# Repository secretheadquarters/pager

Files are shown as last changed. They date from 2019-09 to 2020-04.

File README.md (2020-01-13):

# pager

Raspberry Pi project to act as a kind of pager (or secret communication device)

# Overview

* Raspberry Pi Zero W
 * Connected to red and green LEDs through GPIO
 * With a 20x2 LCD display screen
 * And various extra addons over time (I'm planning a buzzer, USB storage, USB (or Bluetooth) audio, and maybe more)

# Raspberry Pi setup
* Download latest image and write to SD card. 

## On a Linux machine
```
  sudo su
  apt-get install funzip
  
  # Insert SD card
  dmesg 
  # Look at output to work out what device the SD card was recognised as
  
  # Download the latest raspbian image and unzip direct to the sd card 
  # (replace /dev/sdc with the appropriate device)
  wget -O - https://downloads.raspberrypi.org/raspbian_lite_latest | funzip > /dev/sdc
```
## On a Windows machine
* Downnload the image file: https://downloads.raspberrypi.org/raspbian_lite_latest
* Write to an SD card using [Etcher](https://www.balena.io/etcher/)

## Create an email account for the pager
* If you're using gmail:
  * Turn on two-factor authentication
  * Generate an "App Password"

## Configure the SD card
* Copy the files from the [setup/boot] folder to the boot partiton
  * Add an empty file called `ssh` to the boot partition
  * Add a file called `wpa_supplicant.conf` to the boot partition, and fill with your WiFi settings
  * Make sure you use Unix line endings (\n)

## Install the software
* Turn the Raspberry Pi on
* By default, it will appear on the network as "raspberrypi"
* Log in using the standard Raspbian username and password
* Configure the system by downloading the setup script and running it:
  * `curl https://raw.githubusercontent.com/secretheadquarters/pager/master/setup/setup.sh --output setup.sh && chmod +x setup.sh && ./setup.sh`

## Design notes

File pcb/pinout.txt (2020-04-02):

LCD header
----------
GPIO14    DB7   1   2  DB6   GPIO2
GPIO15    DB5   3   4  DB4   GPIO3
GPIO18    DB3   5   6  DB2   GPIO4
GPIO23    DB1   7   8  DB0   GPIO17
GPIO24     E1   9  10  RW    GND
GPIO25     RS  11  12  VO    Contrast 
GND       VSS  13  14  VDD   +5V
GPIO8      E2  15  16  NC
Backlight   A  17  18  K     GND

Buttons header
--------------
Pressing button connects to GND.
Use GPIO with pull-up resistor enabled.

B1  GPIO7
B2  GPIO12
B3  GPIO16

Output header
-------------
Connect red and green LED
Header connects to open-collector NPN transistor
A high signal on GPIO turns transistor on
O1  GPIO21
O2  GPIO20

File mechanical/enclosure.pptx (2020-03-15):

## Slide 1

⌀ 14

⌀ 3.5

Hammond 1591XXDBK FRABS Enclosure 152 x 82 x 50mm Black
Winstar WH2002A-YYH-JT 20x2 LCD Display Yellow/green LED Backlight

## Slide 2

⌀ 16

Hammond 1591XXDBK FRABS Enclosure 152 x 82 x 50mm Black
Winstar WH2002A-YYH-JT 20x2 LCD Display Yellow/green LED Backlight

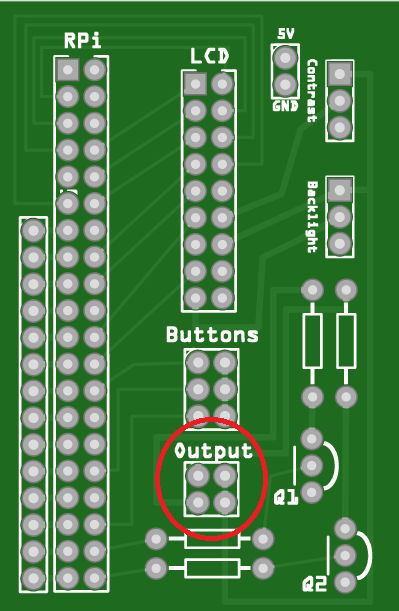
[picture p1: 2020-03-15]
docs/interface-module-pcb-output.png

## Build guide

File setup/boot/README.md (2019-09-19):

Copy these files to the FAT32 partition of your Raspberry Pi SD card before turning it on for the first time. 

Make sure you edit wpa_supplicant.conf to contain your network details first.

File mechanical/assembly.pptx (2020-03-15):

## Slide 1

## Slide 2

Button
Washer
Nut

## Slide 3

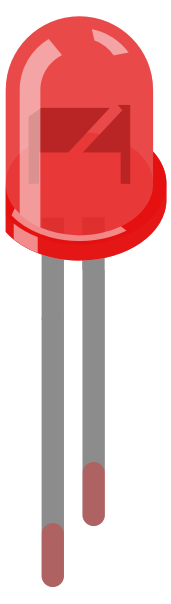
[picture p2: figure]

Anode
+

Cathode

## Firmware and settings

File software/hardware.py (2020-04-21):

import RPi.GPIO
import RPLCD
import gpiozero
from itertools import chain, repeat
import time

_width = 20
_width1 = 21
_lcd = RPLCD.CharLCD(pin_rs=25, pin_rw=22, pin_e=24, pins_data=[3, 15, 2, 14], numbering_mode=RPi.GPIO.BCM)
_lcd.clear()

_green = gpiozero.PWMLED(21)
_red = gpiozero.PWMLED(20)

def write(line1, line2, align1 = "<", align2 = "<"):
    display_line1 = ("{: " + align1 + str(_width) + "}").format(line1)[:_width1]
    display_line2 = ("{: " + align2 + str(_width) + "}").format(line2)[:_width1]
    text = display_line1 + display_line2
    _lcd.clear()
    _lcd.write_string(text)

def scroll_top(text, prepad=0, interpad=int(_width/2), postpad=_width, delay=0.2, repeats=1):
    pre_pad = " " * prepad
    inter_pad = " " * interpad
    post_pad = " " * postpad

    sequence = chain(pre_pad, 
                     chain.from_iterable(repeat(text + inter_pad, repeats - 1)),
                     text + post_pad)

    buffer = ""
    for char in sequence:
        buffer = (buffer + char)[-_width:]
        if len(buffer) == _width:
            _lcd.cursor_pos = (0, 0)
            _lcd.write_string(buffer)
            print("'" + buffer + "'")
            time.sleep(delay)

def clear():
    _lcd.clear()

def green_on():
    _green.on()

def green_off():
    _green.off()

def green_pulse():
    _green.pulse()

def green_blink():
    _green.blink()

def red_on():
    _red.on()

def red_off():
    _red.off()

def red_pulse():
    _red.pulse()

def red_blink():
    _red.blink()

def both_on():
    green_on()
    red_on()

def both_off():
    green_off()
    red_off()

def both_pulse():
    green_pulse()
    red_pulse()

def both_blink():
    green_blink()
    red_blink()

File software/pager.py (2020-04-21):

#!python3

import imapclient
import datetime
import time
import email
import re
import smtplib

import hardware
import config

# Fix the locale so we behave the same in all locations. 
import locale
locale.setlocale(locale.LC_ALL, "C")

from log import logger

imap_server = config.get("IMAP server")
imap_username = config.get("IMAP username")
imap_password = config.get("IMAP password")
smtp_server = config.get("SMTP server")
smtp_username = config.get("SMTP username")
smtp_password = config.get("SMTP password")
smtp_to = config.get("SMTP to")
smtp_from = config.get("SMTP from")

def show(mail):
  message = mail.get("Subject")
  hardware.write("Incoming message", message)
  return "Showed message: " + message

def info(mail):
  logger.debug("info command - ignoring")
  return None
  
def get_logs(mail):
  with open(log.log_filename) as log_file:
    message = log_file.read()
    return message

def command_not_parsed(mail, subject):
  message = "No command found in email subject '" + str(subject) + "'"
  return message

commands = {
  "show": show,
  "info": info,
  "get logs": get_logs,
}

# Some definitions
# email: The email object returned by email.message_from_bytes
#   Note that, to avoid name shadowing the email import, local variables
#   will be called mail, mails, etc. 
# command: The action that should be carried out
# message: The text inside a "show" command

def process_emails(server, commands):
  # It seems that search can get stuck always returning the 
  # same result (usually 0 messages) if you keep asking the 
  # same thing. Doing a SELECT to refresh the search results
  # seems to avoid this. 
  server.select_folder("INBOX")
  message_ids = server.search("ALL")
  uids_and_emails = fetch_emails(server, message_ids)
  logger.debug("Messages: " + str(len(uids_and_emails)))

  for uid, mail in uids_and_emails:
    try:
      command = get_command(commands, mail)
      # TODO: Write execute_command which wraps the command in a try finally and returns an "error" result if it fails.
      result = command(mail)
      send_response(result)
    finally:
      move_mail_to_done(server, uid)

    logger.debug(mail.get('From') + " " + mail.get('Subject'))

def fetch_emails(server, uids):
  return [(uid, email.message_from_bytes(message_data[b'RFC822'])) for uid, message_data in server.fetch(uids, 'RFC822').items()]

def get_command(cmmands, mail):
  # The command is the text at the start of the subject line. 
  # Commands are matched by case insensitive regex using the "C" locale
  # Command matches are performed in an arbitrary order, and the first match will be taken.
  # Commands are passed the email object and can perform further analysis on this as required.

  subject = mail.get("Subject")
  for command_regex in commands.keys():
    if re.match(command_regex, subject, re.I):
      return commands[command_regex]
      
  return lambda mail: command_not_parsed(mail, subject)

def send_response(result):
  if not result:
    logger.debug("No command response (probably an info command)")
    return

  message = email.message.EmailMessage()
  message["Subject"] = "info: Response from pager"
  message["To"] = smtp_to
  message["From"] = smtp_from
  message.set_content(result)

  with smtplib.SMTP_SSL(smtp_server) as smtp:
    smtp.login(smtp_username, smtp_password)
    smtp.send_message(message)

  logger.debug(result)

def move_mail_to_done(server, uid):
  server.move(uid, "Done")

def main():
    hardware.clear()
    hardware.write("TOP SECRET", "Authorised use only.", "^")

    with imapclient.IMAPClient(imap_server) as server:
        server.login(imap_username, imap_password)
        server.select_folder("INBOX")
  
        if not server.folder_exists("Done"):
            server.create_folder("Done")

        while True:
            try: 
                process_emails(server, commands)
                time.sleep(10)
            except KeyboardInterrupt:
                break
            except Exception as ex:
                logger.debug(ex)

main()

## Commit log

2020-03-09 Added PCB for pager
    [pager.fzz]
2020-03-15 Added assembly images
